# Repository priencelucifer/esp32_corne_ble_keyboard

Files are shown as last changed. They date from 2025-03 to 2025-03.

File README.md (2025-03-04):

# Corne BLE ESP32 Keyboard Project 💻⌨️

Welcome to the Corne BLE ESP32 Keyboard Project! This repository contains all the resources needed to build a compact, efficient, and portable split keyboard using the ESP32 microcontroller, an 18650 Lithium-ion battery (2200mAh), and a TP4056 charging module. The keyboard is completely handwired—no PCB is used!

---

## Features 🚀

- **Wireless Bluetooth Connectivity**: Seamlessly connect to multiple devices via BLE.
- **ESP32-Powered**: Leverages the processing power and integrated Bluetooth of the ESP32.
- **Portable Power Supply**: Utilizes a high-capacity 2200mAh 18650 Li-ion battery.
- **Safe Charging**: Incorporates a TP4056 module for secure and efficient battery charging.
- **Handwired Build**: Custom wiring without the use of a PCB.
- **Custom 3D Printed Parts**: Includes a 3D printed case and top plate.
- **Premium Switches**: Equipped with Otemu Blue switches for a satisfying typing experience.

---

## Hardware Components 🛠️

- **ESP32 Microcontroller**: The brain behind the keyboard.
- **18650 Lithium-ion Battery (2200mAh)**: Long-lasting and reliable power source.
- **TP4056 Charging Module**: Manages safe charging of the battery.
- **Otemu Blue Switches**: Provides tactile feedback and crisp actuation.
- **Handwired Connections**: Custom wiring without a PCB.
- **3D Printed Parts**: Custom printed case and top plate.
- **Additional Components**: Key switches, wiring, enclosure materials, and other necessary parts.

---

## Getting Started 🚀

### Prerequisites

Before you begin, ensure you have the following:

- **Hardware**:
  - ESP32 development board
  - 18650 Lithium-ion Battery (2200mAh)
  - TP4056 Charging Module
  - Otemu Blue switches
  - Materials for handwiring (wires, solder, etc.)
  - 3D printed parts (case and top plate)

- **Software**:
  - [Arduino IDE](https://www.arduino.cc/en/software) or [PlatformIO](https://platformio.org/)
  - ESP32 libraries installed

---

## Firmware Overview 📟

The firmware, written in C++ using the Arduino framework, includes functionalities for:

- **Bluetooth Communication**: Establishing and maintaining wireless connections using the [BLEKeyboard ESP32 Library](https://github.com/T-vK/ESP32-BLE-Keyboard) for seamless keyboard emulation.
- **Key Scanning & Debouncing**: Efficiently reading key presses.
- **Power Management**: Coordinating power distribution and safe charging with battery monitoring.
- **Sleep Modes**: Implementing low power consumption using the Deep Sleep Library to extend battery life.

Feel free to explore and modify the code to tailor the keyboard's behavior to your needs!

---

## Media Showcase 📸🎥

### Otemu Blue Switches
<figure>
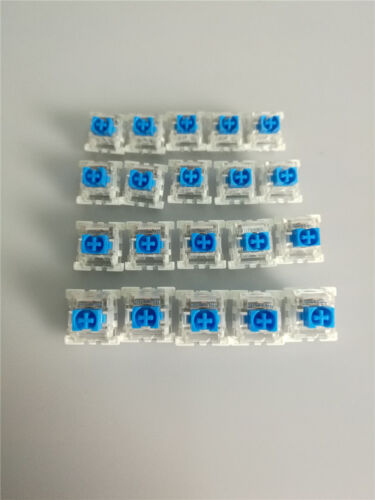
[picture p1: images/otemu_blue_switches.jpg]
Otemu Blue Switches
  
  <figcaption>Figure 1: Otemu Blue Switches installed in the keyboard.</figcaption>
</figure>

### 3D Printed Top Plate
<figure>
  3D Printed Top Plate
  <figcaption>Figure 2: Custom 3D printed top plate.</figcaption>
</figure>

### Back Plate (Physical Build)
<figure>
  Back Plate
  <figcaption>Figure 3: The back plate as part of the physical build (model not available for download).</figcaption>
</figure>

### Handwiring Process
<figure>
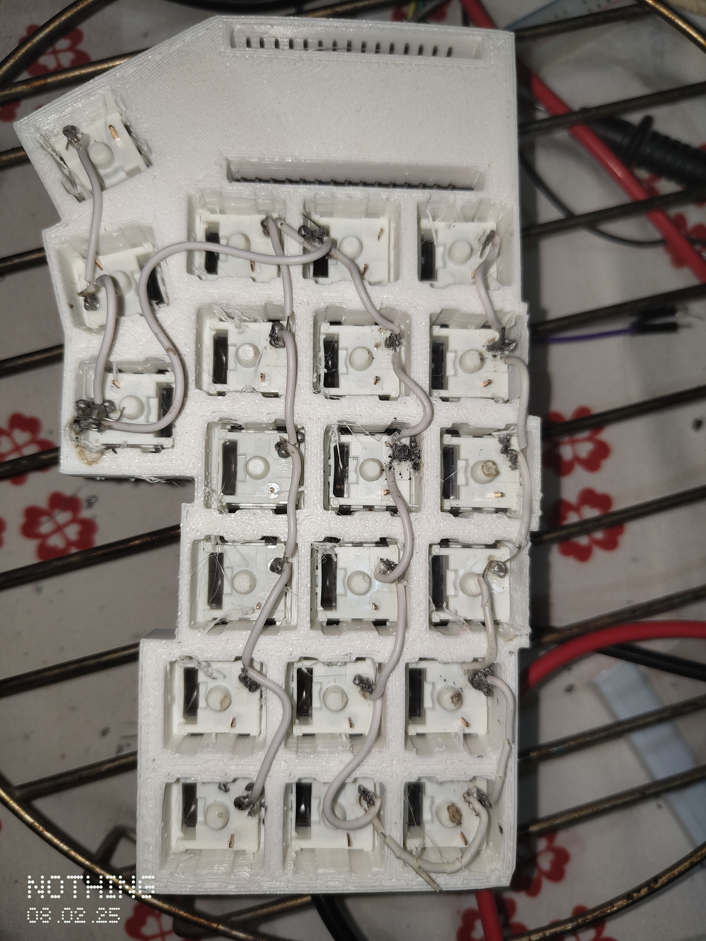
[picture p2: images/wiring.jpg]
Handwiring the Keyboard
  
  <figcaption>Figure 4: Detailed handwiring process.</figcaption>
</figure>

### Charging Module in Action
<figure>
  Charging Module
  <figcaption>Figure 5: Charging module demonstrating battery charging capability.</figcaption>
</figure>

### Working Model Video
<figure>
  <a href="https://youtu.be/gUNzga1hYSY">
    Working Model Video
  </a>
  <figcaption>Figure 6: Watch the demonstration video of the working model on YouTube.</figcaption>
</figure>

---

## 3D Print Models 📐

The 3D print models available for download are located in the `3d_models` folder. They include:

- **Case Model**: `case_model.stl`
- **Top Plate Model**: `top_plate_model.stl`

Feel free to download, modify, and use these files for your own builds!

---

## License 📄

This project is licensed under the [MIT License](LICENSE).

---

## Acknowledgements 🙏

- **ESP32 Team**: Thank you to Espressif for creating such a versatile microcontroller.
- **BLEKeyboard & Deep Sleep Libraries Developers**: Kudos for providing reliable libraries that make wireless keyboard and power management features possible.
- **Community**: Gratitude to all open-source enthusiasts for their continuous support.

---

Happy Coding! 🚀💻⌨️

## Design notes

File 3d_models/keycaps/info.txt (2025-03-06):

these key caps were only made for otemu switches not for cherry mx or any other key switches

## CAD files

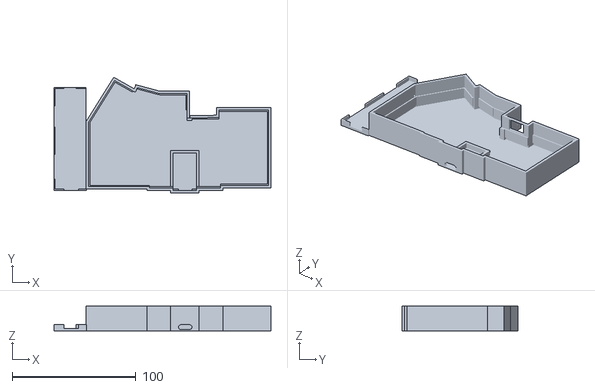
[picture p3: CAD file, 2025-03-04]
3d_models/case_model.stl
175.0 x 93.2 x 20.0

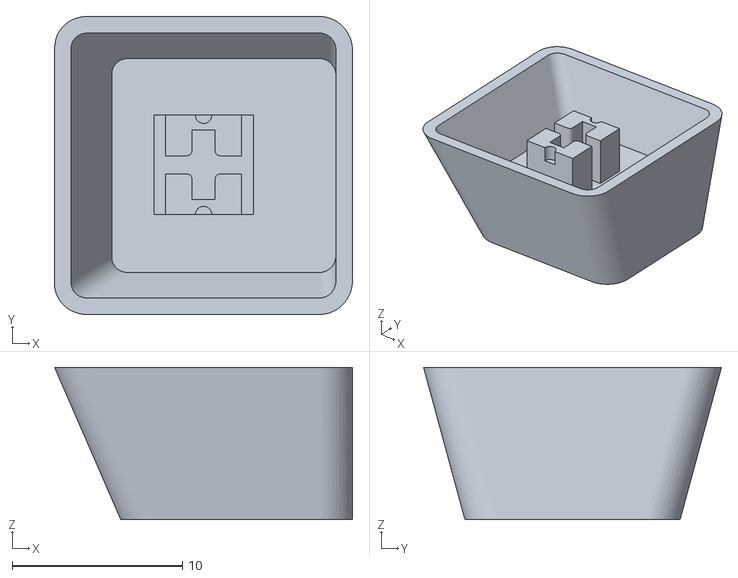
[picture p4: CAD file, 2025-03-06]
3d_models/keycaps/Z.stl
17.5 x 17.5 x 8.96

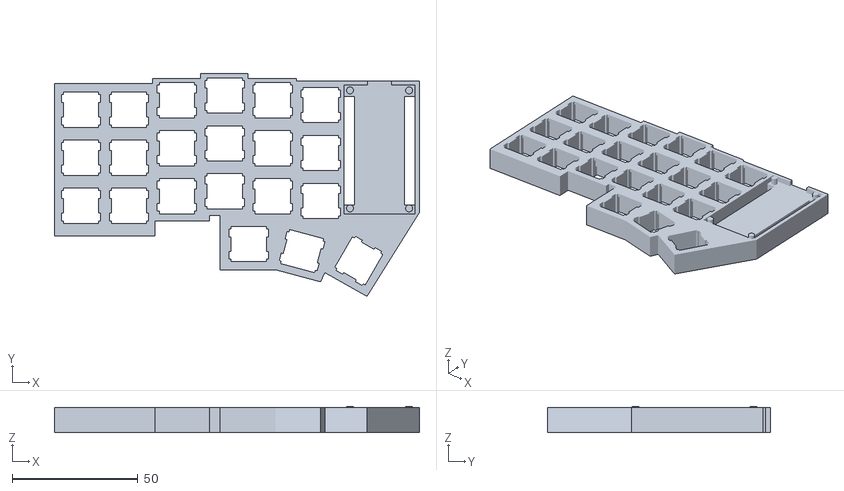
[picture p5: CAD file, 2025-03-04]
3d_models/top_plate_model.stl
145.0 x 88.5 x 10.5

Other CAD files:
3d_models/keycaps/ctrl.stl
3d_models/keycaps/space.stl
3d_models/keycaps/S.stl
3d_models/keycaps/G.stl
3d_models/keycaps/D.stl
3d_models/keycaps/A.stl
3d_models/keycaps/T.stl
3d_models/keycaps/R.stl
3d_models/keycaps/W.stl
3d_models/keycaps/4.stl
3d_models/keycaps/Q.stl
3d_models/keycaps/Y.stl
3d_models/keycaps/F.stl
3d_models/keycaps/V.stl
3d_models/keycaps/C.stl
3d_models/keycaps/B.stl
3d_models/keycaps/E.stl
3d_models/keycaps/X.stl
3d_models/keycaps/shift.stl
3d_models/keycaps/tab.stl

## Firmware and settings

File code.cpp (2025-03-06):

#include <BleKeyboard.h>
#include <esp_sleep.h>  // For deep sleep functionality

// Create the BLE Keyboard instance
BleKeyboard bleKeyboard("ESP32 BLE Keyboard", "MyCompany", 100);

// Total number of keys (21 keys)
const int numKeys = 21;

// Define the GPIO pins for each key in the specified order:
// D13, D12, D14, D27, D26, D25, D33, D32, D15, D2, RX2, TX2, D5, D18, D19, D21, RX0, TX0, D22, D23, D4
int keyPins[numKeys] = {13, 12, 14, 27, 26, 25, 33, 32, 15, 2, 16, 17, 5, 18, 19, 21, 3, 1, 22, 23, 4};

// New key mapping based on your requested configuration:
// Modified key mapping to avoid the Q/shift issue
uint8_t keyMapping[numKeys] = {
  'w',            // 1: D13
  KEY_TAB,        // 2: D12
  's',            // 3: D14
  'a',            // 4: D27
  'y',            // 5: D26
  KEY_LEFT_SHIFT, // 6: D25
  'z',            // 7: D33
  ' ',            // 8: D32
  'q',            // 9: D15 (changed from 'Q' to 'q')
  'g',            // 10: D2
  'r',            // 11: RX2
  'b',            // 12: TX2
  'f',            // 13: D5
  'd',            // 14: D18
  'e',            // 15: D19
  'v',            // 16: D21
  'x',            // 17: RX0
  '4',            // 18: TX0
  'c',            // 19: D22
  KEY_LEFT_CTRL,  // 20: D23
  't'             // 21: D4
};

// Define activation logic for each key:
// All keys are active-low (INPUT_PULLUP) except D2 (index 9) which is active-high.
bool activeHigh[numKeys] = {
  false, false, false, false, false, false, false, false, false, true,
  false, false, false, false, false, false, false, false, false, false, false
};

// Track whether a key is pressed (for auto-repeat)
bool buttonState[numKeys] = {false};
// Store the last time a key event was sent (for auto-repeat timing)
unsigned long lastSent[numKeys] = {0};

// Timing constants (in milliseconds)
const unsigned long initialAutoRepeatDelay = 300;     // first auto-repeat delay: 300 ms
const unsigned long subsequentAutoRepeatDelay = 50;     // subsequent auto-repeat delay: 50 ms

// Per-key flag to know if the first auto-repeat has occurred
bool firstAutoRepeat[numKeys] = {false};

// Variable to track when BLE became disconnected
unsigned long notConnectedStartTime = 0;

void setup() {
  Serial.begin(115200);
  Serial.println("Starting BLE Keyboard...");

  // Initialize each key pin.
  // For keys other than D2 (index 9), use the appropriate internal resistor:
  // - Active-low keys: INPUT_PULLUP.
  // - Active-high keys: INPUT_PULLDOWN.
  // D2 will be reconfigured dynamically based on BLE connection status.
  for (int i = 0; i < numKeys; i++) {
    if (i == 9) { // D2
      pinMode(keyPins[i], INPUT_PULLDOWN);
    } else {
      if (activeHigh[i])
        pinMode(keyPins[i], INPUT_PULLDOWN);
      else
        pinMode(keyPins[i], INPUT_PULLUP);
    }
    buttonState[i] = false;
    lastSent[i] = 0;
    firstAutoRepeat[i] = false;
  }

  bleKeyboard.begin();
}

void loop() {
  bool connected = bleKeyboard.isConnected();
  unsigned long now = millis();

  // Check BLE connection status and enter deep sleep if not connected for more than 10 seconds.
  if (!connected) {
    if (notConnectedStartTime == 0) {
      notConnectedStartTime = now;
    } else if (now - notConnectedStartTime > 10000) { // 10 seconds timeout
      Serial.println("BLE not connected for 10 seconds. Entering deep sleep...");
      // Configure wake-up on D4 (GPIO 4) for low level (button pressed / GND)
      esp_sleep_enable_ext0_wakeup(GPIO_NUM_4, 0);
      esp_deep_sleep_start();
    }
  } else {
    notConnectedStartTime = 0;
  }

  // Flag to indicate if any key was newly pressed in this loop iteration.
  bool newKeyPressed = false;

  // Process each key
  for (int i = 0; i < numKeys; i++) {
    // Special handling for D2 (index 9)
    if (i == 9) {
      if (!connected) {
        // When not connected, set D2 as OUTPUT and blink as an LED.
        pinMode(keyPins[i], OUTPUT);
        // Blink: Toggle every 250 ms (250ms ON, 250ms OFF)
        digitalWrite(keyPins[i], ((now / 250) % 2 == 0) ? HIGH : LOW);
        continue;  // Skip key processing for D2 while blinking.
      } else {
        // When connected, reconfigure D2 as input (active-high) for key reading.
        pinMode(keyPins[i], INPUT_PULLDOWN);
      }
    }

    // Read the key state based on its activation logic.
    bool pressed = activeHigh[i] ? (digitalRead(keyPins[i]) == HIGH)
                                 : (digitalRead(keyPins[i]) == LOW);

    if (pressed) {
      if (!buttonState[i]) {
        // New key press: register immediately.
        buttonState[i] = true;
        firstAutoRepeat[i] = true;  // Mark that the first auto-repeat delay is pending.
        lastSent[i] = now;
        newKeyPressed = true;
        if (connected) {
          Serial.print("Key ");
          Serial.print(keyMapping[i]);
          Serial.println(" pressed");
          bleKeyboard.write(keyMapping[i]);
        }
      } else {
        // Key is held down.
        if (firstAutoRepeat[i]) {
          // Wait for the initial auto-repeat delay (300 ms).
          if (now - lastSent[i] >= initialAutoRepeatDelay) {
            lastSent[i] = now;
            firstAutoRepeat[i] = false;  // First auto-repeat occurred.
            if (connected) {
              Serial.print("Key ");
              Serial.print(keyMapping[i]);
              Serial.println(" auto-repeat (first)");
              bleKeyboard.write(keyMapping[i]);
            }
          }
        } else {
          // Subsequent auto-repeat events every 50 ms.
          if (now - lastSent[i] >= subsequentAutoRepeatDelay) {
            lastSent[i] = now;
            if (connected) {
              Serial.print("Key ");
              Serial.print(keyMapping[i]);
              Serial.println(" auto-repeat");
              bleKeyboard.write(keyMapping[i]);
            }
          }
        }
      }
    } else {
      // Reset state when key is released.
      buttonState[i] = false;
    }
  }
  
  // Debouncing delay:
  // If a new key press was detected this loop, wait 300 ms (to ensure proper debounce before auto-repeat starts);
  // otherwise, use a 50 ms delay.
  if (newKeyPressed)
    delay(300);
  else
    delay(50);
}
